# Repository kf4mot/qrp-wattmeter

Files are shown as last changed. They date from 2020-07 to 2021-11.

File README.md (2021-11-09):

# HF QRP directional wattmeter
A compact directional wattmeter for portable operation. Forward and reflected power is shown simultaneously with 2 LED bargraphs for easy antenna tuning.
Power sensing is done with a tandem match wound on a BN43-202 core. The microcontroller is a ATmega32u4 with USB interface for firmware uploading and serial data out (PC logging, debugging, etc).

[Created with KiCAD ver. 5.0.2](https://kicad.org)

**Things worth knowing**

1. **Firmware is incomplete**. I've been able to do basic hardware checks, but actual power measurement and calibration isn't done.
1. Diodes D1-2, D4-5, and D6-7 are for providing forward bias to the bridge to improve linearity and remove zero offset. 2 devices are shown in each position to give the builder the option of a PTH or SMD package.
1. Op-amps U1 and U2 have PTH and SMD package footprints.
1. The board was designed to fit the Polycase JB-35 enclosure. **Untested** https://www.polycase.com/jb-35 https://github.com/kf4mot/qrp-wattmeter/blob/master/docs/14531129045666870.pdf 

[Licensed under CERN-OHL-S V2. Julian White, 2020](https://www.ohwr.org/project/cernohl/wikis/home)

[Schematic](https://github.com/kf4mot/qrp-wattmeter/blob/master/hardware/qrp_wattmeter.pdf)

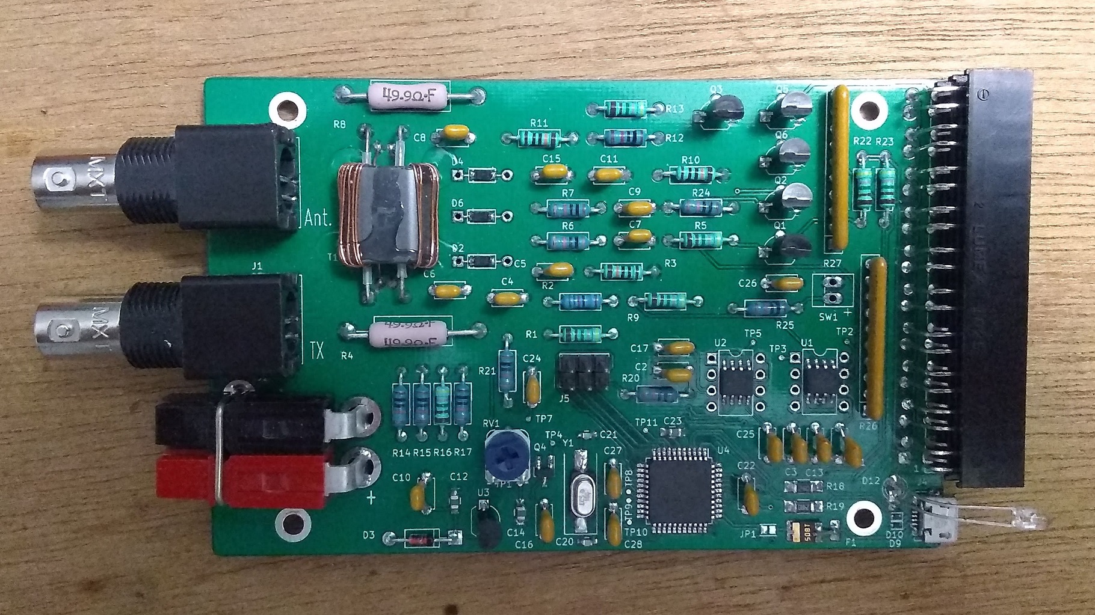
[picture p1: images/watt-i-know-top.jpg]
Complete Board Top


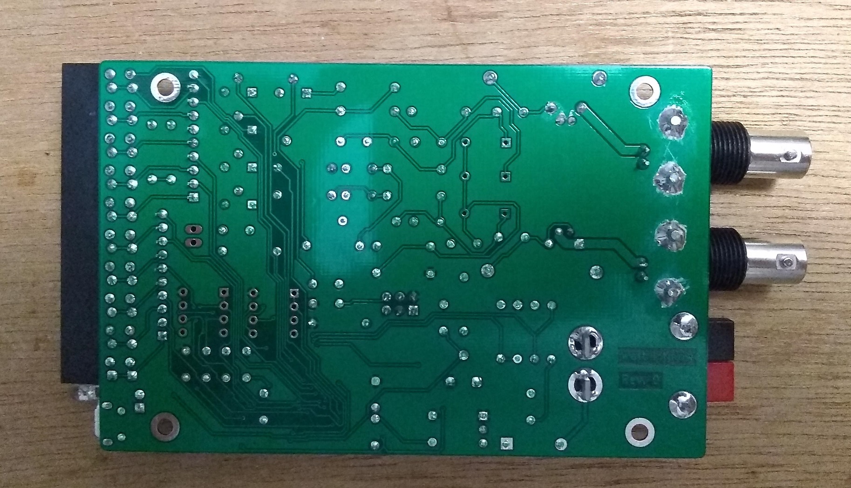
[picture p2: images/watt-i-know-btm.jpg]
BoardTop Board Bottom


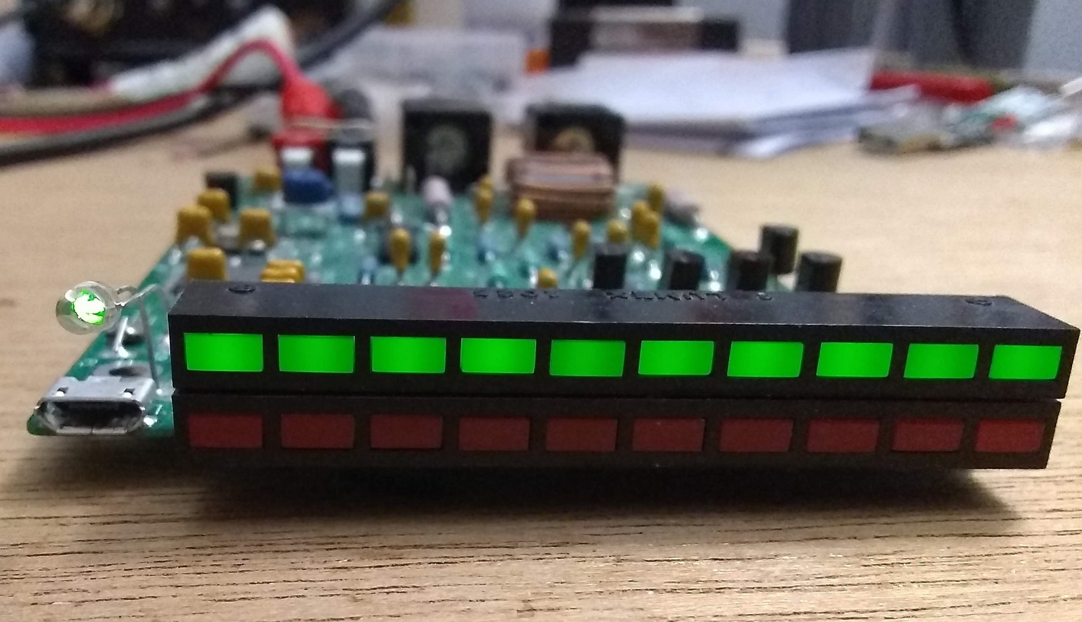
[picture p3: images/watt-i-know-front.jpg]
BoardTop 3D Board Front


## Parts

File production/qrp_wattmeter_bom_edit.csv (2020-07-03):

Component | Part | References | Quantity Per PCB | Part Number | MFG | dsp_value
1 | C_0.1uF_50V_5mm | C1 C2 C3 C4 C5 C6 C7 C8 C9 C10 C11 C13 C15 C16 C17 C22 C24 C25 C26 C27 C28 | 21 | K104K15X7RF53H5 | Vishay | 0.1uF
2 | C_1uF_50V_0805_x7r | C12 C14 C23 | 3 | UMK212BJ105KG-T | Taiyo Yuden | 1uF 50V
3 | C_22pF_0603_50V | C20 C21 | 2 | GRM1885C1H220JA01D | Murata | 22 pF
4 | 1N5711 | D2 D4 D6 | 3
5 | 1n4148 | D3 | 1 | 1n4148
6 | D_Schottky_BAS70H | D1 D5 D7 | 3 | BAS70H,115 | NXP | 70V 70mA
7 | D_TVS_5V_ESD9B5.0ST5G | D9 D10 | 2 | ESD9B5.0ST5G | On Semi | 5V
8 | LED_3mm_Red | D12 | 1 | LTL-4221N | Lite ON | Red
9 | LED_Lumex_SSA_10X_Red | D8 D11 | 2 | SSA-LXH1025ID | Lumex
10 | Polyfuse_500mA | F1 | 1 | MF-MSMF050-2 | Bourns | 500 mA
11 | BNC | J1 J3 | 2 | 731375003 | Molex
12 | Conn_45A_PP | J2 | 1 | 2X 1336G1 and 1X 114555P2 | Anderson
13 | ICSP_header | J5 | 1
14 | USB_B_Micro | J4 | 1 | 105017-0001 | Molex | USB
15 | SolderJumper_2_Open | JP1 | 1
16 | BS170 | Q1 Q2 Q3 Q5 Q6 | 5 | BS170-D27Z | On Semi
17 | BSH203 | Q4 | 1 | BSH203,215 | NXP
18 | R_100K_6.3mm | R3 R10 R11 | 3 | MFR-25FTF52-100K | Yageo | 100K
19 | R_10K_6.3mm | R6 R7 R12 R14 R15 R17 R20 R21 R24 R25 | 10 | MFR-25FRF52-10K | Yageo | 10K
20 | R_24_sm1206 | R18 R19 | 2 | CR1206-FX-24R0ELF | Bourns | 24R
21 | R_4.7K_6.3mm | R1 R5 R9 R13 R16 R22 R23 | 7 | MFR-25FTF52-4K7 | Yageo | 4.7K
22 | R_49.9_2W_th | R4 R8 | 2 | MOS2CT52R49R9F | KOA | 49.9
23 | R_562_6.3mm | R2 | 1 | MFR-25FBF52-562R | Yageo | 562
24 | R_Array_5X_2K_TH | R26 R27 | 2 | 4610X-102-202LF | Bourns | 2K
25 | R_POT_5K_3306F-1-502 | RV1 | 1 | 3306F-1-502 | Bourns | 5K
26 | SW_Push_TH | SW1 | 1 | Generic Push Button |  | 10W / 100W
27 | Transformer_BN43-202_tandem_match | T1 | 1 | BN43-202
28 | 78L05 | U3 | 1 | L78L05ABZ-TR | ST Micro | +5V
29 | ATmega32U4-AU | U4 | 1 | ATMEGA32U4-AU | Atmel | ATMEGA32U4
30 | LMC6482 | U1 U2 | 2 | LMC6482IMX/NOPB | TI | LMC6482
31 | Crystal_16M_SMT | Y1 | 1 | ECS-160-20-3X-TR | ECS | 16 MHz

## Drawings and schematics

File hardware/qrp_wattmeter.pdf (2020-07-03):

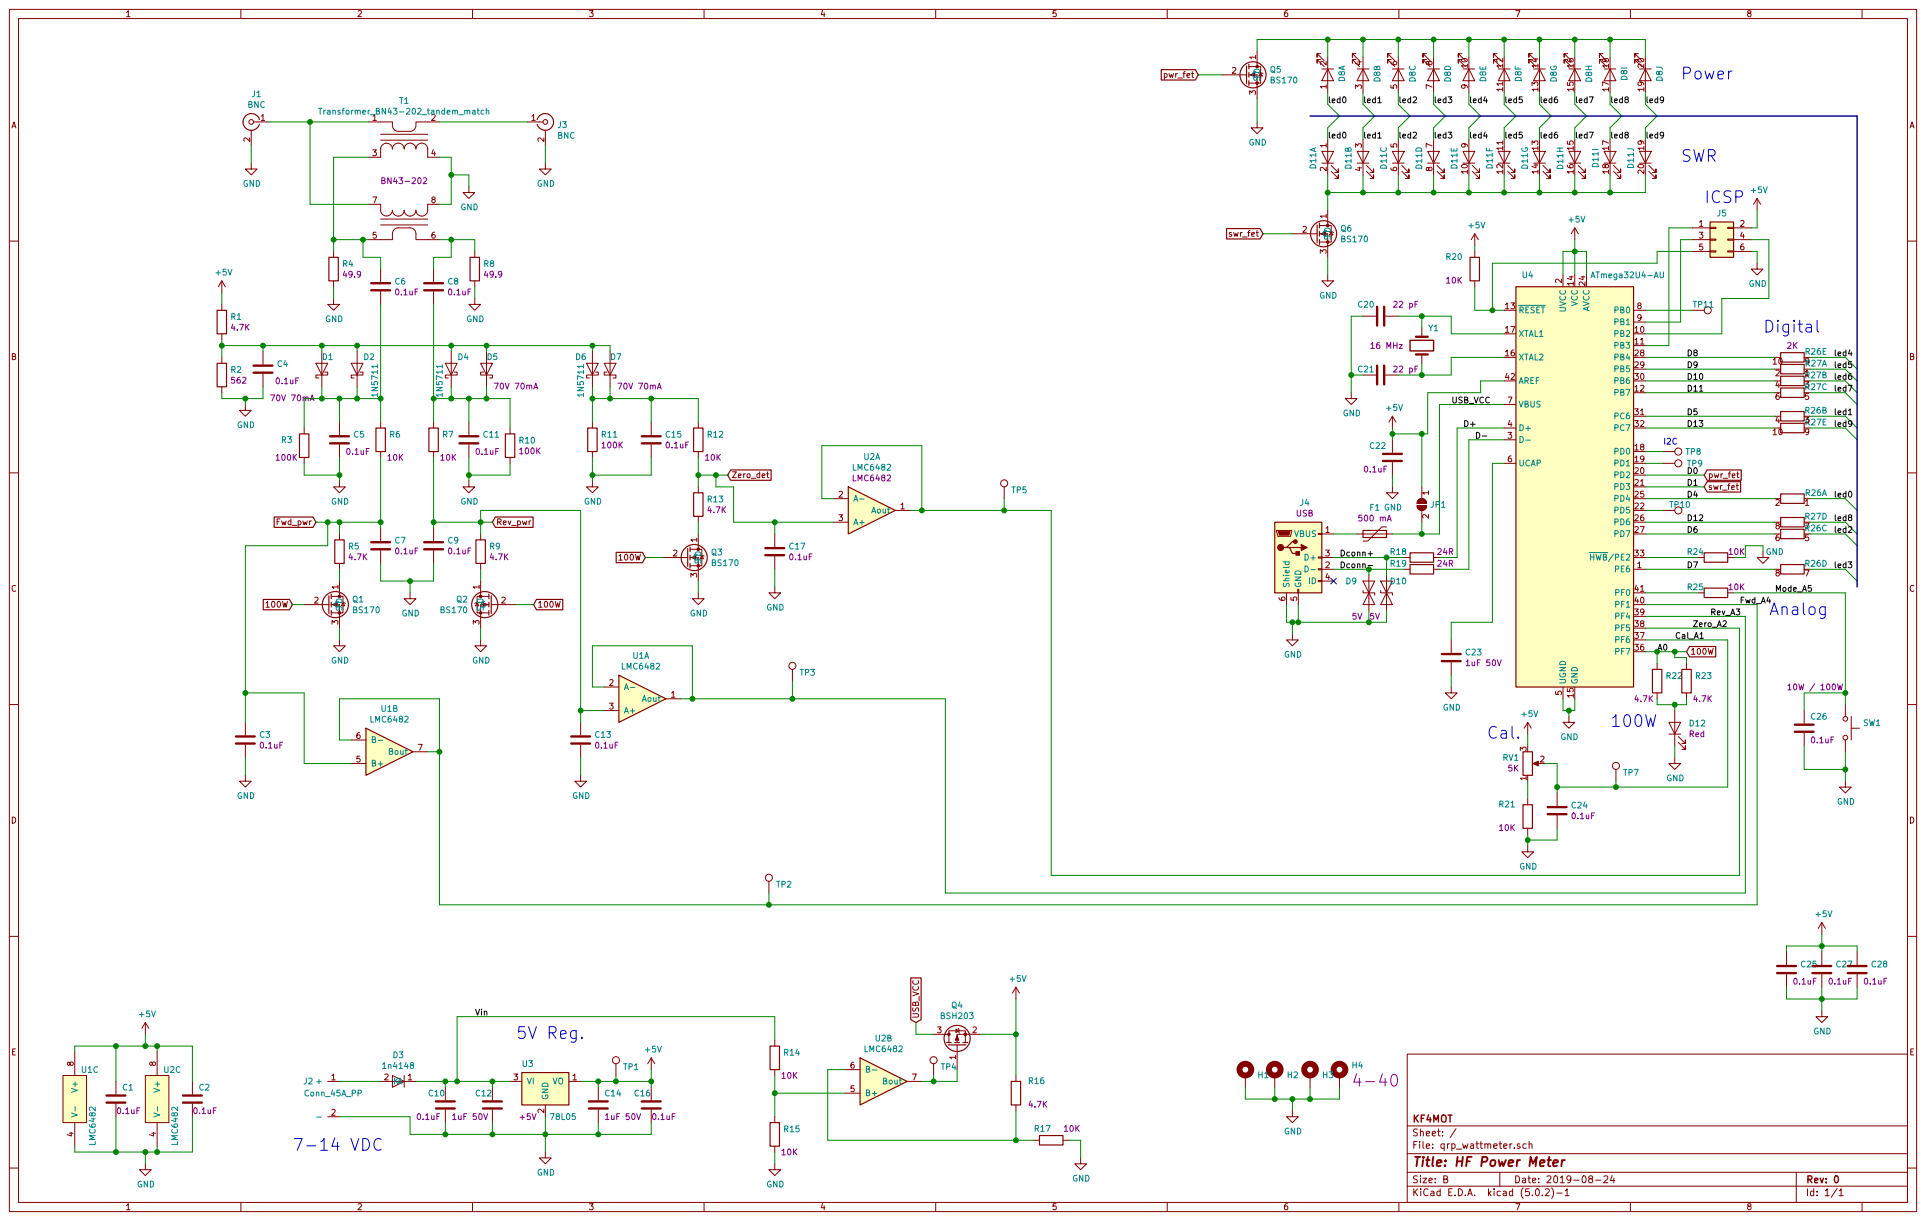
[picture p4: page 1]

USB_VCC | 1 PB2 27 PB4 31 PC7

30 PC6 | led7

Id: 1/1 Title: HF Power Meter

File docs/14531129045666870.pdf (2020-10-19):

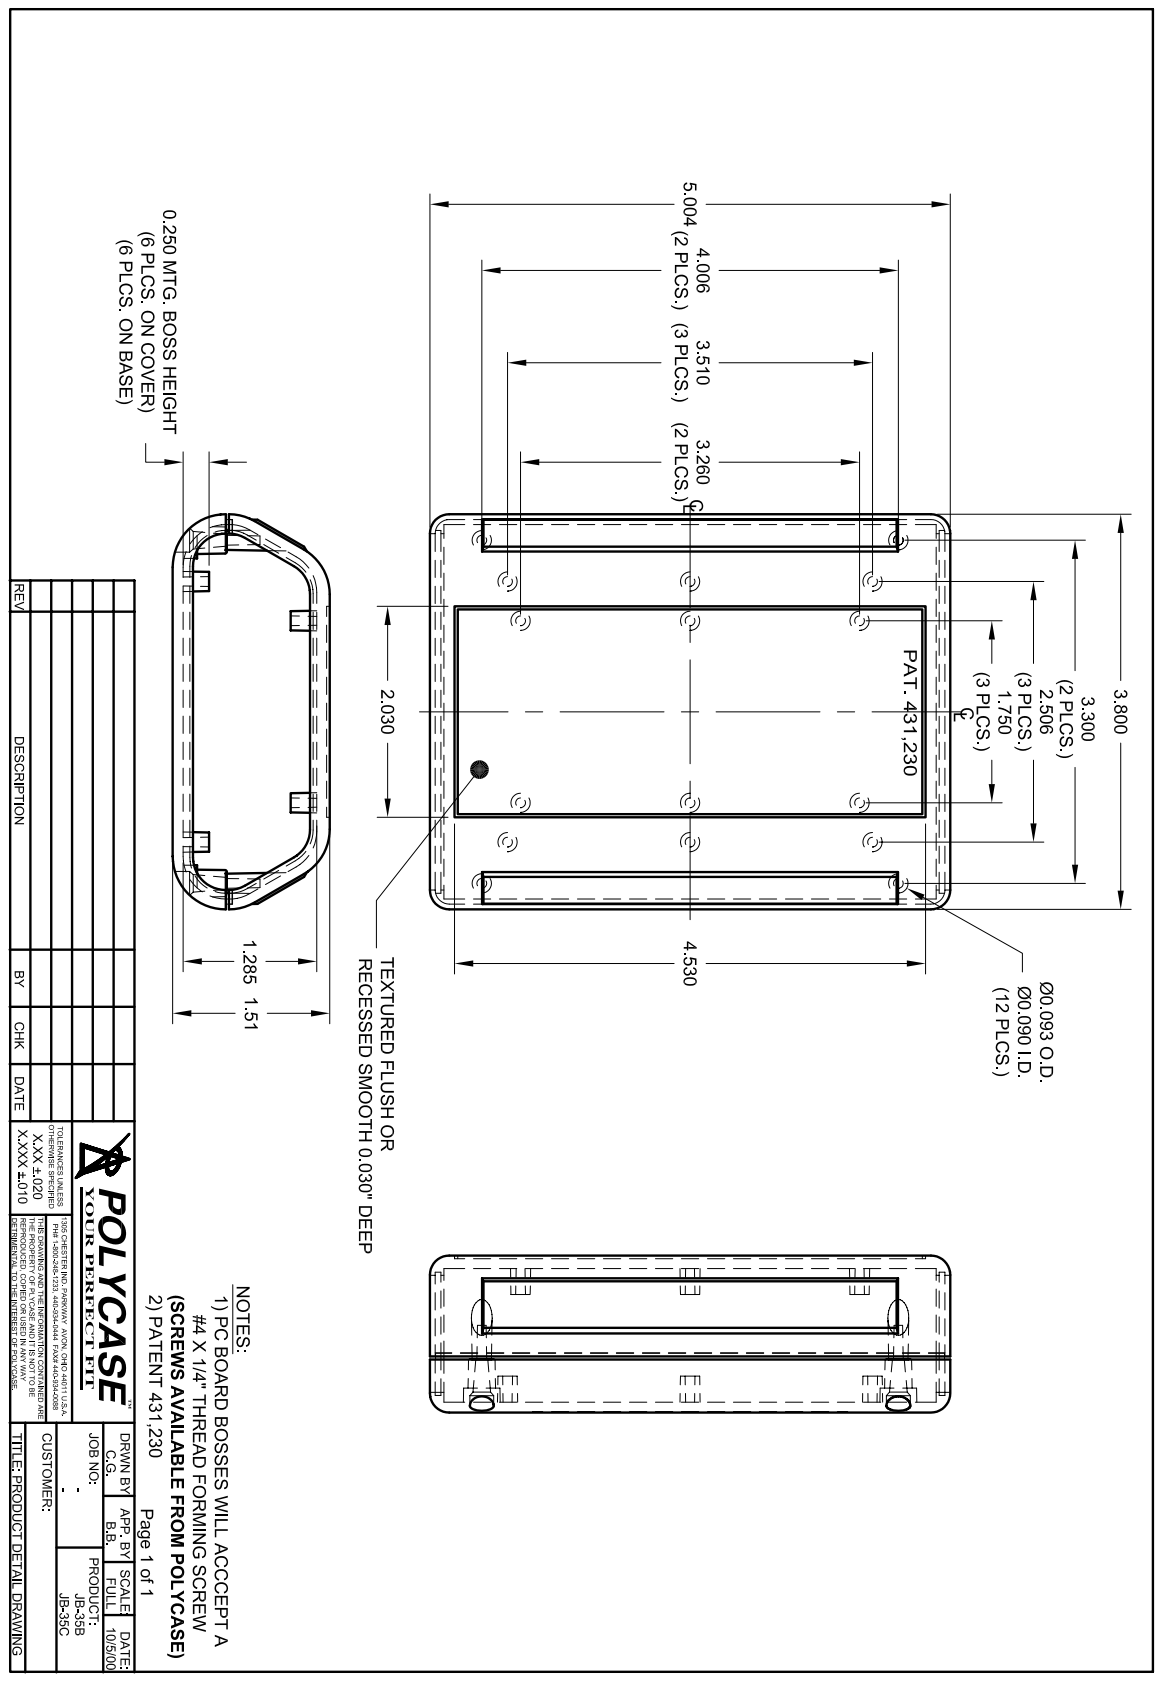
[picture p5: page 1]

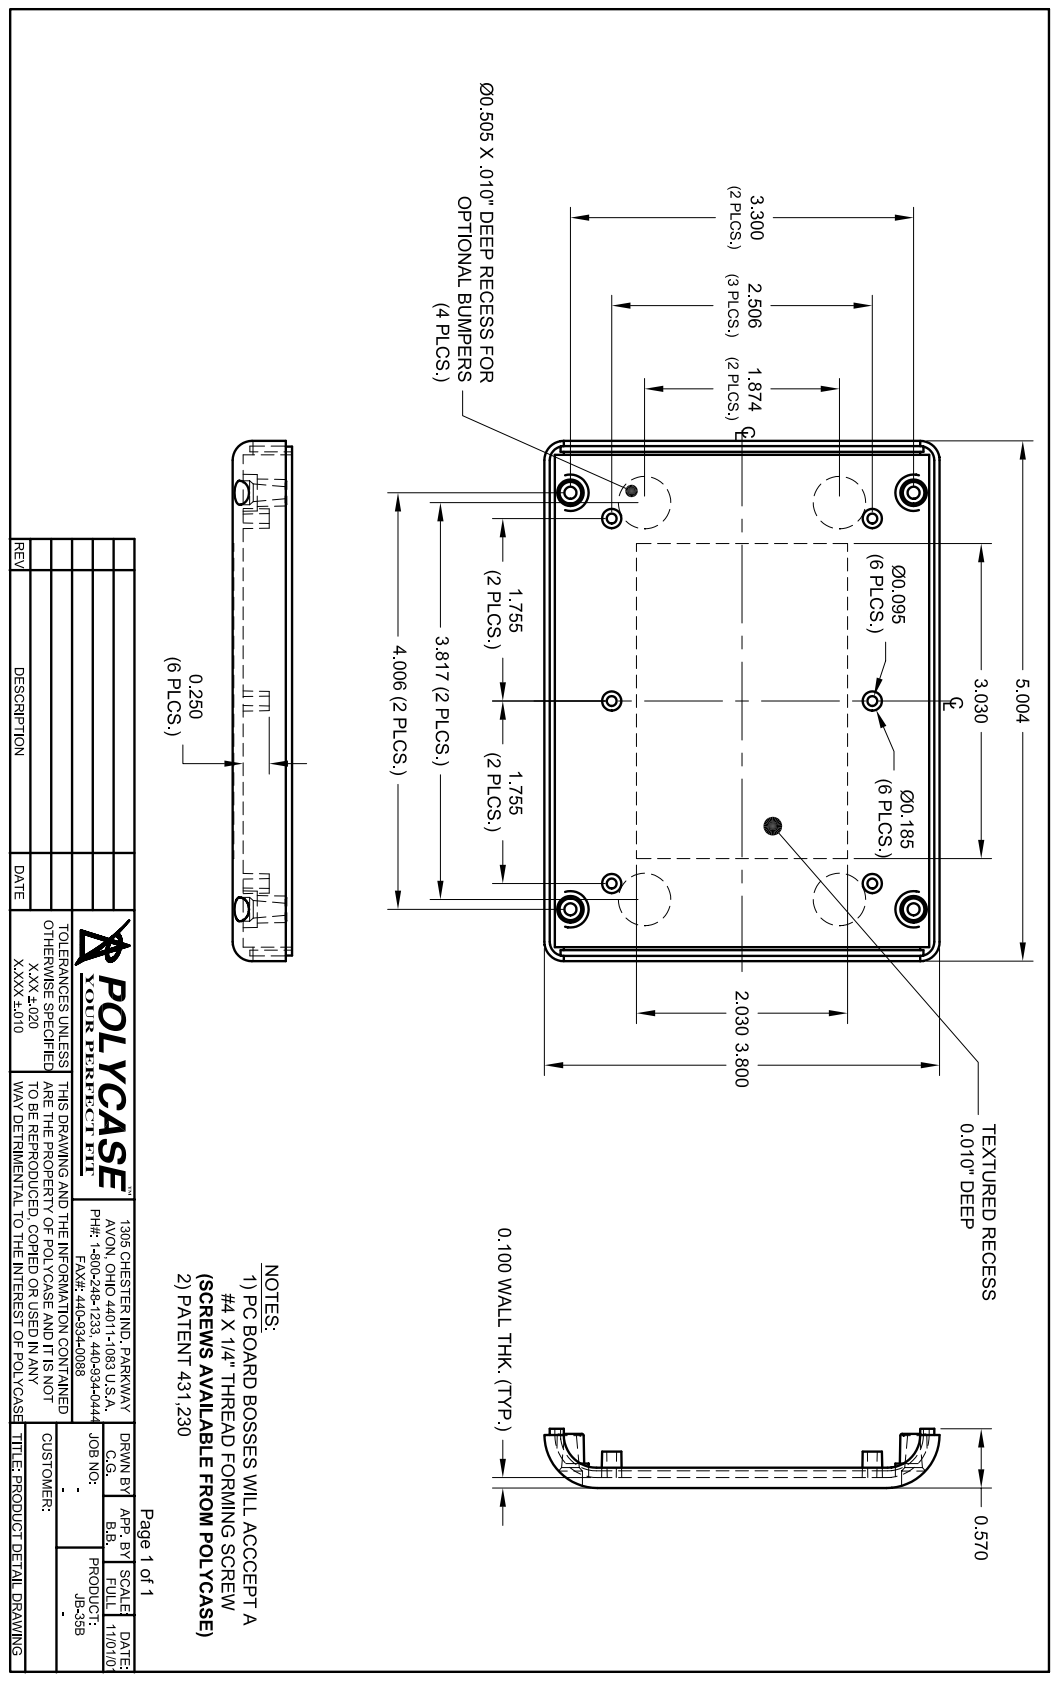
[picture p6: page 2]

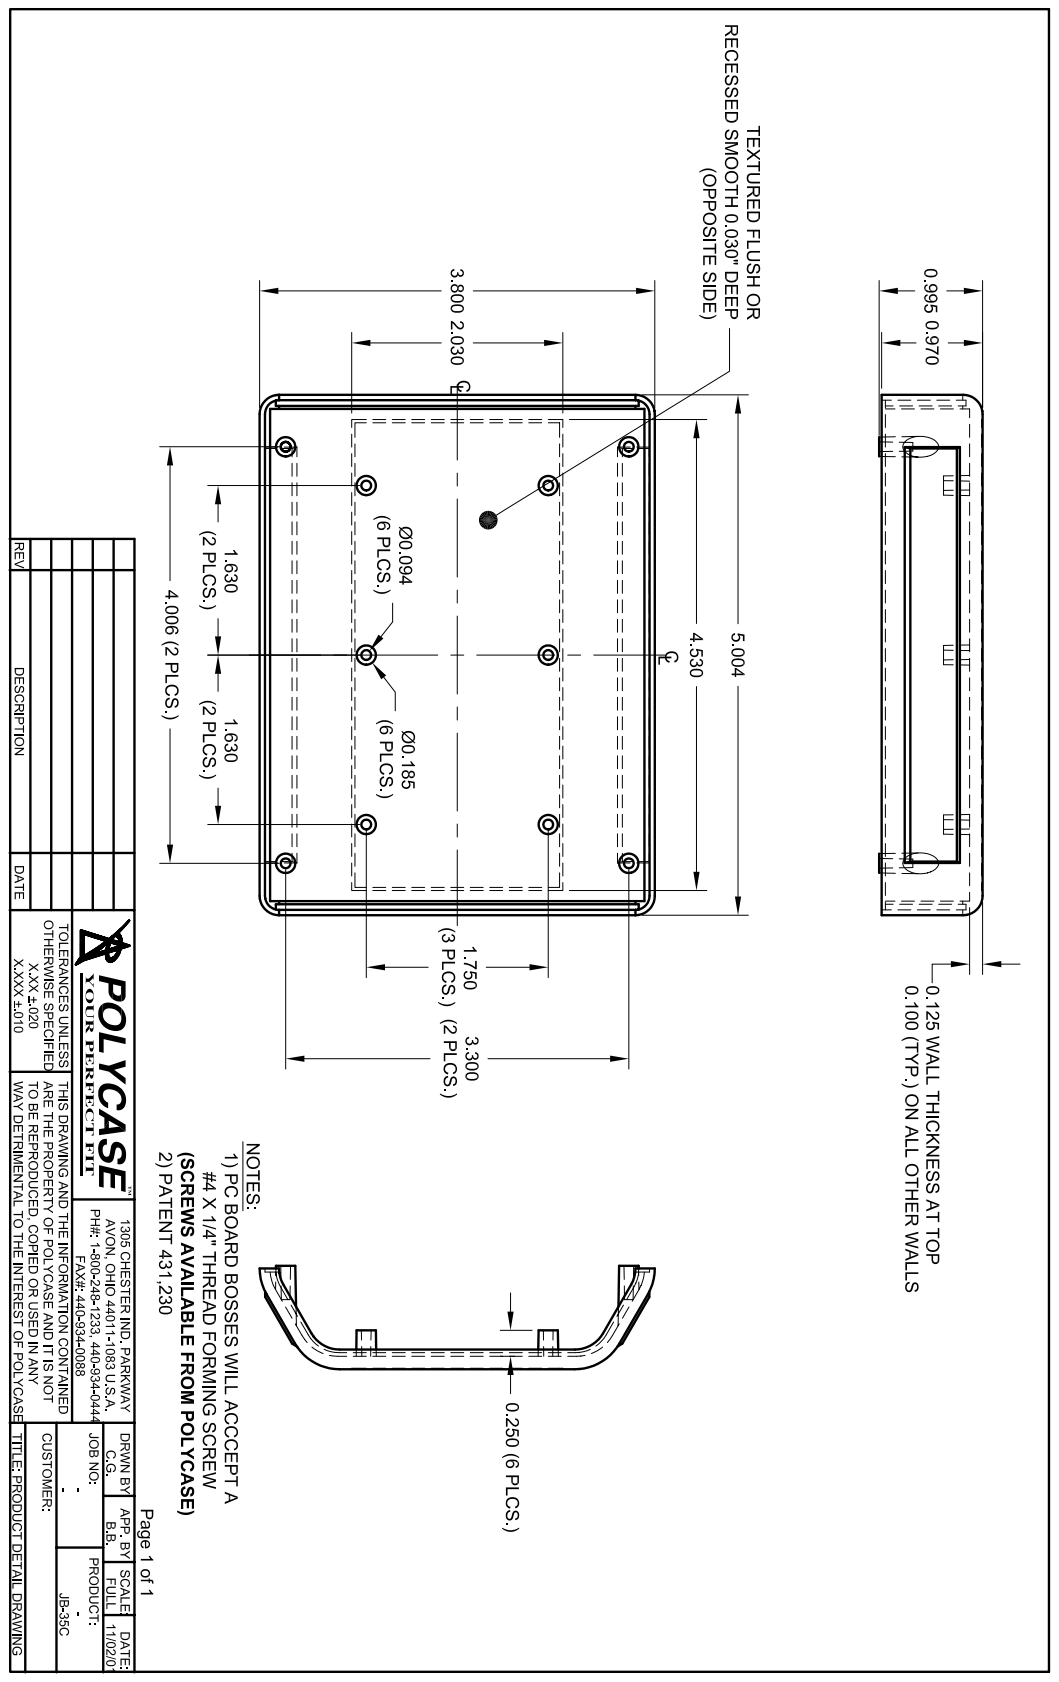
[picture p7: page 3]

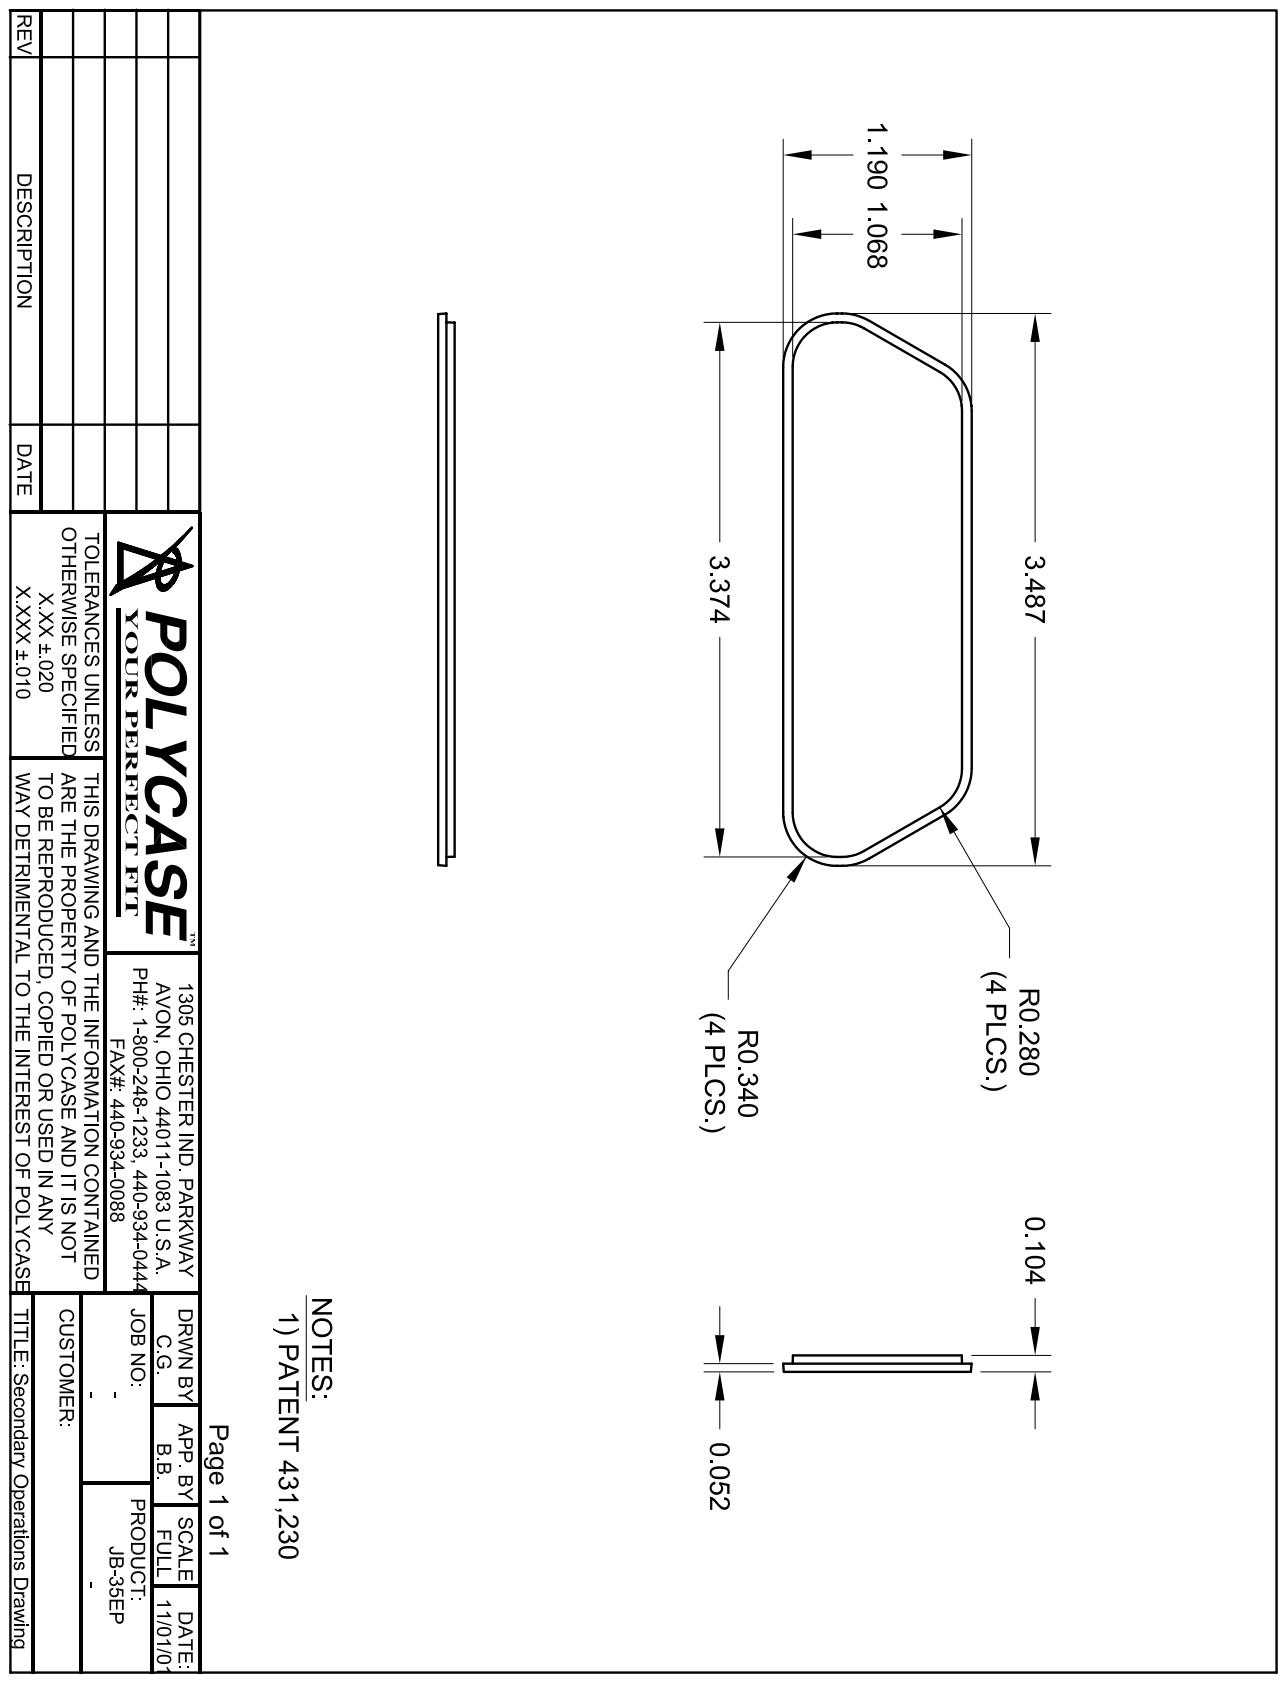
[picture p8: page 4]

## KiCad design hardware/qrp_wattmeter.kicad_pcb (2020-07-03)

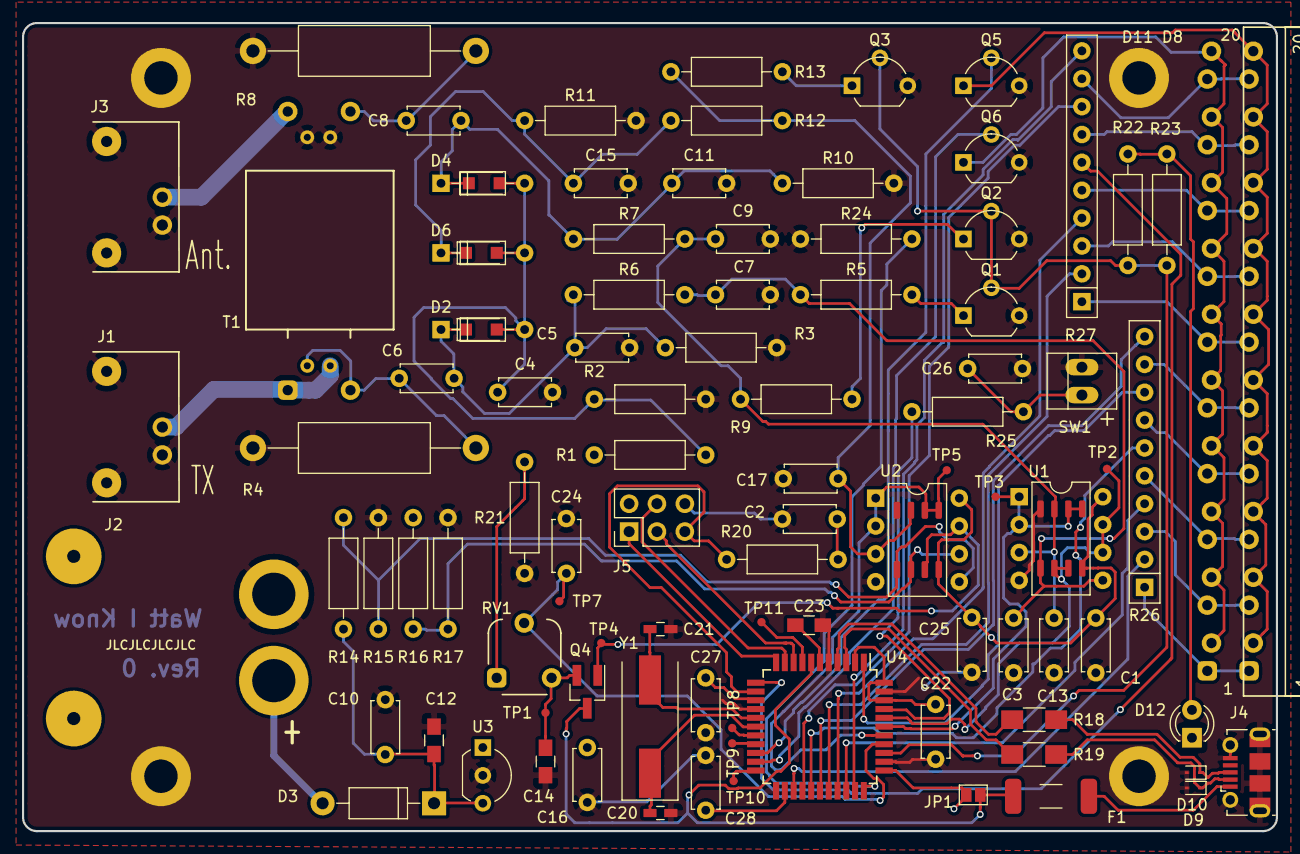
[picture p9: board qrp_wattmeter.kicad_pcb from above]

Board: 2 copper layers, 114.3 x 73.7 mm, 100 parts (0 on the bottom side), 72 nets.

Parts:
C1, C2, C3, C4, C5, C6, C7, C8, C9, C10, C11, C13, C15, C16, C17, C22, C24, C25, C26, C27, C28: C_0.1uF_50V_5mm; C_Disc_D4.7mm_W2.5mm_P5.00mm
C12, C14, C23: C_1uF_50V_0805_x7r; C_0805_HandSoldering
C20, C21: C_22pF_0603_50V; C_0603_HandSoldering
D1, D5, D7: D_Schottky_BAS70H; D_SOD-123F
D2, D4, D6: 1N5711; D_DO-35_SOD27_P7.62mm_Horizontal
D3: 1n4148; D_DO-41_SOD81_P10.16mm_Horizontal
D8, D11: LED_Lumex_SSA_10X_Red; Lumex_SSA-LXH1025ID_10X_led
D9, D10: D_TVS_5V_ESD9B5.0ST5G; D_SOD-923
D12: LED_3mm_Red; LED_D3.0mm
F1: Polyfuse_500mA; Fuse_SMD1812
H1, H2, H3, H4: MountingHole_Pad_4-40; MountingHole_4-40_Pad
J1, J3: BNC; bnc_molex_0731375003
J2: Conn_45A_PP; PP45_RA_pcb
J4: USB_B_Micro; USB_Micro-B_Molex-105017-0001
J5: ICSP_header; Pin_Header_Straight_2x03_Pitch2.54mm
JP1: SolderJumper_2_Open; GS2
Q1, Q2, Q3, Q5, Q6: BS170; TO-92_Molded_Wide
Q4: BSH203; SOT-23_Handsoldering
R1, R5, R9, R13, R16, R22, R23: R_4.7K_6.3mm; R_Axial_DIN0207_L6.3mm_D2.5mm_P10.16mm_Horizontal
R2: R_562_6.3mm; R_Axial_DIN0207_L6.3mm_D2.5mm_P10.16mm_Horizontal
R3, R10, R11: R_100K_6.3mm; R_Axial_DIN0207_L6.3mm_D2.5mm_P10.16mm_Horizontal
R4, R8: R_49.9_2W_th; R_Axial_DIN0414_L11.9mm_D4.5mm_P20.32mm_Horizontal
R6, R7, R12, R14, R15, R17, R20, R21, R24, R25: R_10K_6.3mm; R_Axial_DIN0207_L6.3mm_D2.5mm_P10.16mm_Horizontal
R18, R19: R_24_sm1206; R_1206_HandSoldering
R26, R27: R_Array_5X_2K_TH; R_Array_SIP10
RV1: R_POT_5K_3306F-1-502; Pot_Bourns_3306F
SW1: SW_Push_TH; PINHEAD1-2
T1: Transformer_BN43-202_tandem_match; Transformer_Amidon-BN43-202
TP1, TP2, TP3, TP4, TP5, TP7, TP8, TP9, TP10, TP11: Test_smt; tpsm
U1, U2: LMC6482; DIP-8+SOIC-8
U3: 78L05; TO-92_Inline_Wide
U4: ATmega32U4-AU; LQFP-44_10x10mm_Pitch0.8mm
Y1: Crystal_16M_SMT; Crystal_SMD_HC49-SD

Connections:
100W: Q1.2, Q2.2, Q3.2, R22.1, R23.1, U4.36
+5V: C1.1, C2.1, C14.1, C16.1, C22.1, C25.1, C27.1, C28.1, J5.2, JP1.1, Q4.2, R1.1, R16.2, R20.2, RV1.3, TP1.1, U1.8, U2.8, U3.1, U4.2, U4.14, U4.24, U4.34, U4.42, U4.44
/Cal_A1: C24.1, RV1.2, TP7.1, U4.37
/D4: R26.2, U4.25
/D5: R26.4, U4.31
/D6: R26.6, U4.27
/D7: R26.8, U4.1
/D8: R26.10, U4.28
/D9: R27.2, U4.29
/D10: R27.4, U4.30
/D11: R27.6, U4.12
/D12: R27.8, U4.26
/D13: R27.10, U4.32
/D+: R18.1, U4.4
/D-: R19.1, U4.3
/Dconn+: D10.1, J4.3, R18.2
/Dconn-: D9.1, J4.2, R19.2
/Fwd_A4: TP2.1, U1.6, U1.7, U4.40
/Mode_A5: C26.1, R25.1, SW1.1
/Rev_A3: TP3.1, U1.1, U1.2, U4.39
/Vin: C10.1, C12.1, D3.1, R14.1, U3.3
/Zero_A2: TP5.1, U2.1, U2.2, U4.38
/led0: D8.1, D11.1, R26.1
/led1: D8.3, D11.3, R26.3
/led2: D8.5, D11.5, R26.5
/led3: D8.7, D11.7, R26.7
/led4: D8.9, D11.9, R26.9
/led5: D8.11, D11.11, R27.1
/led6: D8.13, D11.13, R27.3
/led7: D8.15, D11.15, R27.5
/led8: D8.17, D11.17, R27.7
/led9: D8.19, D11.19, R27.9
Fwd_pwr: C3.1, C7.1, R5.1, R6.2, U1.5
GND: C1.2, C2.2, C3.2, C4.2, C5.2, C7.2, C9.2, C10.2, C11.2, C12.2, C13.2, C14.2, C15.2, C16.2, C17.2, C20.2, C21.2, C22.2, C23.2, C24.2, C25.2, C26.2, C27.2, C28.2, D9.2, D10.2, D12.1, H1.1, H2.1, H3.1, H4.1, J1.2, J2.2, J3.2, J4.5, J4.6, J5.6, Q1.3, Q2.3, Q3.3, Q5.3, Q6.3, R2.2, R3.2, R4.2, R8.2, R10.2, R11.2, R15.2, R17.1, R21.1, R24.1, SW1.2, T1.4, T1.8, U1.4, U2.4, U3.2, U4.5, U4.15, U4.23, U4.35, U4.43
unnamed: C4.1, D1.2, D2.2, D4.2, D5.2, D6.2, D7.2, R1.2, R2.1
unnamed: C5.1, C6.2, D1.1, D2.1, R3.1, R6.1
unnamed: C6.1, R4.1, T1.3, T1.5
unnamed: C8.1, R8.1, T1.6
unnamed: C8.2, C11.1, D4.1, D5.1, R7.1, R10.1
unnamed: C15.1, D6.1, D7.1, R11.1, R12.1
unnamed: C20.1, U4.17, Y1.1
unnamed: C21.1, U4.16, Y1.2
unnamed: C23.1, U4.6
unnamed: D3.2, J2.1
unnamed: D8.2, D8.4, D8.6, D8.8, D8.10, D8.12, D8.14, D8.16, D8.18, D8.20, Q5.1
unnamed: D11.2, D11.4, D11.6, D11.8, D11.10, D11.12, D11.14, D11.16, D11.18, D11.20, Q6.1
unnamed: D12.2, R22.2, R23.2
unnamed: F1.2, J4.1
unnamed: J1.1, T1.1, T1.7
unnamed: J3.1, T1.2
unnamed: J5.1, U4.11
unnamed: J5.3, U4.9
unnamed: J5.4, U4.10
unnamed: J5.5, R20.1, U4.13
unnamed: Q1.1, R5.2
unnamed: Q2.1, R9.2
unnamed: Q3.1, R13.2
unnamed: Q4.1, TP4.1, U2.7
unnamed: R14.2, R15.1, U2.5
unnamed: R16.1, R17.2, U2.6
unnamed: R21.2, RV1.1
unnamed: R24.2, U4.33
unnamed: R25.2, U4.41
unnamed: TP8.1, U4.18
unnamed: TP9.1, U4.19
unnamed: TP10.1, U4.22
unnamed: TP11.1, U4.8
Rev_pwr: C9.1, C13.1, R7.2, R9.1, U1.3
USB_VCC: F1.1, JP1.2, Q4.3, U4.7
Zero_det: C17.1, R12.2, R13.1, U2.3
pwr_fet: Q5.2, U4.20
swr_fet: Q6.2, U4.21
